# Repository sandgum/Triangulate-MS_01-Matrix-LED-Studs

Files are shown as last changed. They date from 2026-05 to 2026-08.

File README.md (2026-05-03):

# MatrixStuds

## Description
Tiny 10x10mm ear studs (inspired by Mitxela) with 16 LEDs on each, arranged in a 4x4 matrix. Each matrix is controlled by an Analog Devices MAX32660 microcontroller paired with a Bosch BMA530 accelerometer to react to orientation changes. Each stud features a tiny 3.7v-3.3v step-down converter to accept rechargeable Li-ion cells. All tied up together in a CNC'd steel enclosure.

Screenshot 2026-04-04 at 11 23 14 am

## PCB (Studs)
### Overview
* 4-layer double-stacked rigid PCB (8 layers when assembled)
* Matrix on one "part" of PCB, other electronics on other "part"
* Features interconnect pads on back of each PCB to interface between the two "parts"
* 0.4mm thickness, 0.8mm total stacked thickness
* Features 1mm pads for programming, power pins

### Schematic
Screenshot 2026-04-04 at 11 30 57 am

### PCB Layout
Screenshot 2026-04-04 at 11 31 59 am

*Top Layer*

Screenshot 2026-04-04 at 11 32 11 am

*Bottom Layer*

Screenshot 2026-04-04 at 11 38 30 am

*3D Model (Bottom Side)*

Screenshot 2026-04-04 at 11 38 48 am

*3D Model (Top Side)*

## PCB (Charging Board)
## Overview
* 4-layer double-stacked rigid PCB (8 layers when assembled)
* Side 1:
*   Battery charging circuitry for two batteries (fuel gauge and charger)
*   USB-C Port
*   ATMega328P microcontroller for controlling lights
* Side 2:
*   9x WS2812B 2mm NeoPixel Lights
*   Reset SPDT switch for MCU

### Schematic
Screenshot 2026-05-03 at 11 30 13 am

### PCB Layout
Screenshot 2026-05-03 at 11 30 37 am

*Top Layer*

Screenshot 2026-05-03 at 11 31 29 am

*Bottom Layer*

Screenshot 2026-05-03 at 12 21 00 pm

*3D Model (Top Side)*

Screenshot 2026-05-03 at 12 21 12 pm

*3D Model (Bottom Side)*

## Enclosure
### Overview (Studs)
* CNC stainless steel construction
* Two-part design, one for battery side, one for top side
* Translucent PP diffuser over LED matrix
* Push-lock mechanism two secure both sides
* Permanent power wire going from battery side to top side in accent colour
* Points on back of top side for rotational stability while on ear

### Overview (Charging Dock)
* CNC steel upper construction, 3D-printed plastic lower construction
* Battery charging GND connection made through upper case, positive connection made through insulated copper springs
* Magnets to secure studs
* USB-C charging, SoC indication through adressable RGB strip

### Images (Studs)
Screenshot 2026-04-04 at 11 36 01 am
Screenshot 2026-04-04 at 11 36 17 am
Screenshot 2026-04-04 at 11 36 41 am
Screenshot 2026-04-04 at 11 36 59 am

### Images (Charging Dock)
Screenshot 2026-05-03 at 12 22 40 pm
Screenshot 2026-05-03 at 12 23 12 pm
Screenshot 2026-05-03 at 12 23 26 pm
Screenshot 2026-05-03 at 12 23 36 pm
Screenshot 2026-05-03 at 12 23 51 pm

## Bill of Materials (Coming soon)

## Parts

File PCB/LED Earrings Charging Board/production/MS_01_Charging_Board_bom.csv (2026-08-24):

Designator | Footprint | Quantity | Value | LCSC Part #
C1, C3, C5, C57, C58, C59, C6, C60 | 0201 | 8 | 1uF
C10, C9 | 0201 | 2 | 10pF
C11, C12, C13, C14, C15, C16, C17, C18, C19, C20 | 0201 | 10 | 100nF
C2, C4 | 0201 | 2 | 4.7uF
C7, C8 | 0201 | 2 | 22pF
D1, D2, D3, D4, D5, D6 | 0201 | 6 | LED
D10, D11, D12, D13, D14, D16, D17, D18, D9 | LED_WS2812B-2020_PLCC4_2.0x2.0mm | 9 | WS2812B-2020
J1_2, J1 | HRO_TYPE-C-31-M-12 | 2 | TYPE-C-31-M-12
Q3, Q4, Q5, Q6, Q7, Q8 | SOT-23 | 6 | BSS138
R1, R11, R12, R2 | 0201 | 4 | 1.5k
R10, R4, R5, R8 | 0201 | 4 | 1.18k
R22, R23, R24, R25, R26, R27, R28, R29, R3, R30, R31, R32, R33, R34, R35, R36, R37, R38, R39, R40, R41, R42, R43, R44, R9 | 0201 | 25 | 10K
R6, R7 | 0201 | 2 | 5.1k
SW1 | SW_SPDT_PCM12 | 1 | SW_SPDT
TP1, TP3 | TestPoint_Pad_D1.5mm | 2 | Battery+
TP10 | TestPoint_Pad_D1.0mm | 1 | DTR
TP11 | TestPoint_Pad_D1.0mm | 1 | 5V
TP12 | TestPoint_Pad_D1.0mm | 1 | RESET_2
TP13 | TestPoint_Pad_D1.0mm | 1 | DOUT_MCU
TP14, TP16, TP17 | TestPoint_Pad_D1.0mm | 3 | TestPoint
TP18 | TestPoint_Pad_D1.0mm | 1 | DIN_LED
TP19 | TestPoint_Pad_D1.0mm | 1 | VCC_LED
TP2, TP4 | TestPoint_Pad_2.0x2.0mm | 2 | GND
TP20 | TestPoint_Pad_D1.0mm | 1 | VCC_O_LED
TP23 | TestPoint_Pad_D1.0mm | 1 | RESET_1
TP5 | TestPoint_Pad_D1.0mm | 1 | MOSI
TP6 | TestPoint_Pad_D1.0mm | 1 | MISO
TP7 | TestPoint_Pad_D1.0mm | 1 | SCK
TP8 | TestPoint_Pad_D1.0mm | 1 | TX
TP9 | TestPoint_Pad_D1.0mm | 1 | RX
U1, U2 | QFN50P300X300X100-17N | 2 | BQ24075RGTR
U12, U13 | 21-0555B_W80B1-1_MXM | 2 | MAX17048X+T10
U3 | QFN-32-1EP_5x5mm_P0.5mm_EP3.1x3.1mm | 1 | ATmega328P-M
U4 | SOT-23 | 1 | XC6206P332MR-G-SOT23 | XC6206P332MR-G
Y1 | OSC_X322516MLB4SI | 1 | X322516MLB4SI

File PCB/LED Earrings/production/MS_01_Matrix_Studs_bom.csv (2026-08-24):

Designator | Footprint | Quantity | Value | LCSC Part #
A1 | BGA6N40P3X2_120X80X59 | 1 | BMA530
C1, C5 | 0201 | 2 | 1uF
C2 | 0402 | 1 | 10uF
C3 | 0201 | 1 | 4.7uF
C4 | 0201 | 1 | 100nF
D1, D10, D11, D12, D13, D14, D15, D16, D2, D3, D4, D5, D6, D7, D8, D9 | 0201 | 16 | LED
MOUSE-BITE-1MM-3MM_4, MOUSE-BITE-1MM-3MM_3, MOUSE-BITE-1MM-3MM_2, MOUSE-BITE-1MM-3MM | mouse-bite-1mm-3mm | 4 | VAL**
R1, R2 | 0201 | 2 | 4.7k
TP1 | TestPoint_Pad_D1.0mm | 1 | SWDIO
TP10, TP18 | TestPoint_Pad_D1.0mm | 2 | P0.5
TP11 | TestPoint_Pad_D1.0mm | 1 | GND
TP12, TP23 | TestPoint_Pad_D1.0mm | 2 | P0.9
TP13, TP6 | TestPoint_Pad_D1.0mm | 2 | P0.8
TP14, TP21 | TestPoint_Pad_D1.0mm | 2 | P0.11
TP15, TP7 | TestPoint_Pad_D1.0mm | 2 | P0.10
TP16, TP8 | TestPoint_Pad_D1.0mm | 2 | P0.7
TP17, TP9 | TestPoint_Pad_D1.0mm | 2 | P0.6
TP19, TP20 | TestPoint_Pad_D1.0mm | 2 | P0.12
TP2 | TestPoint_Pad_D1.0mm | 1 | SWDCLK
TP22 | TestPoint_Pad_D1.0mm | 1 | GND1
TP3 | TestPoint_Pad_D1.0mm | 1 | BAT+
TP4 | TestPoint_Pad_D1.0mm | 1 | BAT-
TP5 | TestPoint_Pad_D1.0mm | 1 | VIO
U1 | 21-100264_90-100089_MXM | 1 | MAX32660GTG+T
U2 | CONV_XCL206B333CR-G | 1 | XCL202B331ER-G

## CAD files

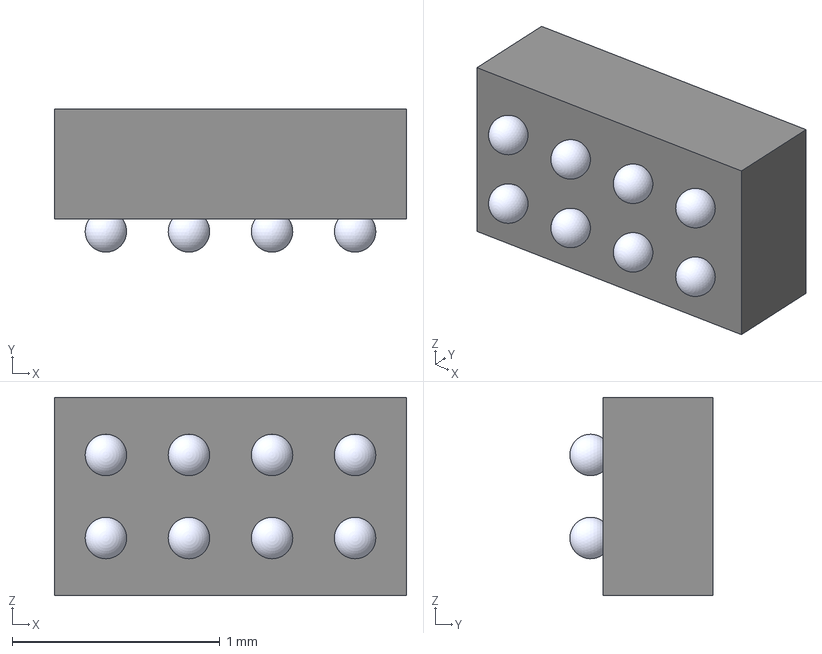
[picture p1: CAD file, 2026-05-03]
PCB/Additional Components/ul_MAX17048X-T10/MAX17048X T10 3D Model STEP.STEP
1.70 x 0.69 x 0.955 mm
Body_Solid1
Body002_Solid1
BALL_0001
BALL_0002
BALL_0003
BALL_0004
BALL_0005
BALL_0006
BALL_0007
BALL_0008

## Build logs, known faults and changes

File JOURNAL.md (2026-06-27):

<!--
  This journal is auto generated by Stasis.
-->

# 5/3/2026 1 AM - Routed Charging Dock PCB

_Time spent: 6h_

I started to route the PCB for the charging dock. When I first imported the footprints for each of the components, they seemed to be too large to fit on the tiny 15x30(ish) millimeter PCB, but that's when I started to employ some crazy Tetris skills to fit everything in. I started with placing the components for the battery charger circuits as efficiently as possible, and I ended up with a very small number of total vias upon routing the tracks.

Screenshot 2026-05-03 at 11.22.06 am

Still, I figured that I would need to take a multi-part board approach in this design by creating two separate boards and stacking them together (just like how the studs themselves are made). The LEDs and the USB-C port took up the most amout of space, so I initially placed them on a separate board to the main charger block.

Placing the MAX17048X+T10 chips and routing their signals, I realised that maybe I would be able to fit almost everything on one board, especially since I had more than enough space left in the middle for a USB-C port and the ATMega328P to comfortably fit in. This is what I ended up doing, with the LEDs and a mysterious switch for the ATMega328P still being located on a separate board. In the remaining spaces left on the main part of the board, I squeezed in test points that will be used for programming and monitoring the signals that go between the MCU and its various peripherals.

Screenshot 2026-05-03 at 11.22.54 am

Screenshot 2026-05-03 at 11.22.33 am

I employed the same stacked board design as I did in the studs themselves, with some test points between the two boards that will be connected together with a low-temp solder after assembly (to make sure any other pre-soldered parts don't fall off). For the connection to GND, I decided not to use a test point but instead used the through-holes required for the shield in the USB-C port on the main board. The through-hole pins extend a bit outwards, so accompanying holes on the PCB fit into them which also provides robust alignment for everything.

Routing everything was quite difficult especially given JLCPCB's minimum via size was quite large compared to the tiny board I had. Nevertheless, I was able to fit in a largely uninterrupted ground plane and robust traces for power to everything as well as multiple test pads for debugging and programming. Considering I use the same 0.4mm minimum 4-layer PCB thickness, the whole board exclusing components will be 0.8mm thick, just enough to fit into the enclosure without serious modifications to it.

I chose to panelise the two parts of the PCB for cheaper assembly costs (just like the studs), and connected them together using a mouse bite footprint.

Now it was time to troubleshoot. I ran the Design Rules Checker and found hundreds of errors. This was, however, mostly due to clearance issues and me forgetting to reduce the allowable pad clearance (as JLCPCB can support it). After edding those rules and clearing up some minor issues, the PCB was fully done!

Screenshot 2026-05-03 at 11.23.34 am






# 4/20/2026 7 AM - Created Charging Dock Schematic

_Time spent: 4.5h_

With the basic outline and features I wanted to include in the charging dock finalised, I started to research the parts which I would include, the first one being the battery charging ICs.

These will be the cornerstone of the dock board, and they need to charge fast without an overly complicated external circuit. After a lot of research (which included charging ICs from Analog Devices and various others from Texas Instruments), I settled on using the BQ24075 from Texas Instruments for a numbr of reasons. First, it has a standalone mode which does not require linking it up to a microcontroller via I2C (which would require extra firmware development for drivers), and it achieves very fast charging speeds at 800mA, which can ideally charge the 40mAh batteries of the earrings in around 3 minutes! This charging current would have to be limited in this use case for safety, as the li-ion batteries would risk potential damage by charging that fast.



Implementing the application circuit for the charging IC was simple, and I made an extra modification by adding a transistor-based logic level shifter to the charging signal output. The reson for this will become apparent later.



Routing the power inputs of the two battery charging chips to the VBUS pins on a USB-C port (and making sure to terminate the CC pins with 5.1k resistors), The board now accomplishes all the functions that I intended it to.



However, I wanted this charging dock board to have some extra functionality, so I decided to include a full microcontroller and a series of lights to show charging status. The simplest MCU chip to implement in the design is the ATMega328P, which comes in a tiny 5x5mm package and comes with Arduino IDE support for easy programming.



This rather overkill MCU will allow for the board to have a series of LED lights, specifically a string of 12 WS2812 NeoPixel RGB Lights for a really nice indicator system. To know the state of charge of the batteries, I opted to use two MAX17048X+T10 fuel gauge chips as they can easily communicate over I2C, have Arduino support through a library, and are absolutely tiny.





Finally, the fuel gauge chips and the battery chargers (remember the logic level shifters?) were connected to the digital I/O of the MCU through logic level shifters, and the whole PCB schematic is now done! Time to stuff all of this into a PCB and see if it actually fits!











# 4/8/2026 4 PM - Modelled charging dock/case

_Time spent: 2h_

The studs themselves were done, so I started creating the charging dock for them that would enable actual daily use. Initially, I wanted to create something like an earbuds case, which has the benefit of having a battery of its own to charge the earbuds on the go. This, however, would require a lot of space, both for a large enough battery to make it worthwhile, and for three separate battery charging circuits (one for the internal battery, and two for the studs). 

Plus, the charging dock will be very small to complement the tiny size of the studs, so fitting all of those extra components in would make for an aesthetically inappealing disproportionate form.

Also, I'm already targeting at least one full day of constant use for the studs, so realistically it makes sense for the user to have a charging dock permanently plugged in at home, and charge their studs when they come back.

Screenshot 2026-04-08 at 9.54.15 pm
Screenshot 2026-04-08 at 9.54.41 pm
Screenshot 2026-04-08 at 9.55.01 pm

So with this use case in mind, I started designing a charging "dock", not a case. I began with two nice cutouts for the battery sections to slide into, where conveniently both the positive and negative contacts for the battery were easily accessible. The case for the stud itself is the negative contact, and the positive contact for the battery is exposed on the outside, so a spring-loaded pogo pin on the dock can easily interface with that, and the metal in the dock can connect to the battery's ground.

Below the space for the studs, I created a plastic bottom cap with enough space for a 15x33mm PCB with two small battery charging circuits and a USB-C power port. The whole assembly has been goven the same yellow-and-silver colour scheme as the studs, which gives it a fun and playful look.

Now I will move on to creating the charging PCB, and then I can finally start developing firmware.





# 4/4/2026 5 AM - Modeled Metal Enclosure

_Time spent: 4h_

After getting the PCB design finalised, I started work on the CNC metal enclosure that everything will be housed in. This has to be extremely small and precise (hence the lack of any 3D printing in this project) and also fulfil the purpose of being jewelry. Since my design will also use a split architecture with the battery being on one piece of the stud and the electronics being on the other side, I would also have to find a way to route power through the user's ear.

I started with the section of the stud which holds the battery, which has a very simple one-piece construction. The LIR1045 battery slots into the enclosure, with the positive contact being exposed outwards and the ground gontact being connected to the metal. On the other side of the enclosure, there is a 1.5mm thick tube for a 1mm thick rod to slide into. This will be how the two sides of the stud connect together.
 
Screenshot 2026-04-04 at 11.20.37 am

I wanted to have this connection be made through screw threads, however that will require twisting the whole stud, which can't be allowed due to the additional positive wire that runs directly between the two halves. I had to come up with a solution to this, which involved a tiny push-lock mechanism between the two halves.

Screenshot 2026-04-04 at 11.19.59 am

There is a small divot in the tube on the battery section in which a corresponding bump on the rod pops into. There are additional channels cut into the rod to allow for bending, effectively creating a rudimentary spring. The size of the cutouts are made as large as possible for easy machineability.

Screenshot 2026-04-04 at 11.21.20 am

Now onto the top section of the stud. This is also a single-piece component, with the exception of a thin PP film on the top to help diffuse the individual LEDs. The geometry for this part is much more complicated, with holes cut out for temporary wires to program the MCU inside. There's also a hole cut out on the side for the battery positive wire to route through.

Screenshot 2026-04-04 at 11.21.51 am

One of the most important features of the top part of the stud is the addition of three small points that face towards the user's ear. These are to constrain the rotation of the top part of the stud by slightly digging into the ear, as any rotation is immediately noticeable due to its square shape. Since the points are only 0.5mm tall, they won't hurt the ear at all, barely being noticeble during daily wear.

Screenshot 2026-04-04 at 11.22.12 am

The final enclosure design of the studs has been confimed, so now it's time to design their charging dock!

Screenshot 2026-04-04 at 11.22.30 am








# 3/27/2026 4 AM - Finished PCB Design

_Time spent: 3.5h_

After designing the first board for each matrix stud (which holds the matrix itself) it was now time to focus my attention towards laying out the main control components on their own "layer" of the board. Squeezing the MCU, the voltage regulator, the accelerometer and the connection pade for all the various signals took some quirky rotation and arrangement of parts, but eventually I was able to fit everything on the board.

Screenshot 2026-03-27 at 3.03.04 pm

The hardest part of this project by far was actually routing all the required signals in only 4 layers, while also having no blind or buried via manufacturing capabilities. This made every via take up space on all layers on the board, and I had to get very close to JLCPCB's minimum copper trace width and via size to pack everything in. This took roughly two hours of brain-breaking work, only for me to be faced with HUNDREDS of errors when I ran KiCAD's Design Rules Checker.

Screenshot 2026-03-27 at 3.03.37 pm

Most of the rule breaches were from copper traces that were mere micrometers too close to other nets, and a lot of errors came from courtyard breaches (which I chose to ignore, as I was definitely breaching the recommended courtyards for each component, but that was the only way to make all of them fit in an 8x8mm rounded square). This took more work, until I finally cleared up all copper shorts and soldermask aperture bridges.

I will be getting JLCPCB to assemble these studs, as they use extremely small 0201 sized passive components. JLC requires a PCB size of at lest 10x10mm for this service, so I grouped both sides of the PCB together with tiny mouse bites. These were also connected to two tabs which provide JLC with enough area to make fiducial holes for PCB assembly.

Screenshot 2026-03-27 at 3.07.42 pm

Now that the final PCB is done, I can export it to a 3D model and start designing the enclosure along with the charging circuit for the earrings!





# 3/24/2026 3 AM - Designed PCB schematic and started PCB design

_Time spent: 3.25h_

After deciding on the basic SMD components for the MatrixStuds, I started to compile together a simple schematic. As the microcontroller, the IMU and the voltage regulator all require a very small number of external components, implementing the necessary application schematics for their operation was quite straightforward.

Screenshot 2026-03-24 at 2.06.32 pm

After that, I created the schematic for the simple 4x4 LED matrix, which uses a total of 8 GPIO pins on the microcontroller. The pins for this matrix are not actually connected to the microcontroller in the schematic, but are connected to touch points that correspond wigth equivalent contacts that connect to the microcontroller. This is my solution to two significant problems:
1. There are not enough layers in a 4-layer board to support the routing and vias for both the control electronics and LED matrix
2. A 2-sided board is pretty much mandatory to minimise space taken up, but that incurs additional assembly costs

Having the control electronics (MCU, accelerometer, voltage regulator) on a separate one-sided board, while having the LEDs on another one-sided board would solve these problems, as when these two boards are stacked up, it effectively makes an 8-layer 2-sided PCB for the price of a 4-layer one-sided PCB.

The touch points are on the backside of each board, and allow the two boards to interface with each other.

A couple more touch points have also been added to the front side of the electronics board to allow for programming and the battery connection.

With the super simple schematic done, it was time to move onto designing the PCB, which, as it turns out, is a completely different beast.

That doesn't really worry me as I start laying out the matrix of LEDs on a really nice 8x8mm square board outline with rounded edges. Routing all the signals is trivial, and there is enough space between each LED to  allow for relatively large vias that are nowhere close to the minimum size JLCPCB can manufacture without a price jump. To make the board look cooler (because let's face it, the whole point of matrix LED studs is aesthetics) the LEDs have been tilted at a 45° angle, which also comes with the benefit of easier routing and a denser matrix.

Screenshot 2026-03-24 at 2.07.30 pm

Screenshot 2026-03-24 at 2.07.40 pm

Now it's time to route the PCB that houses the control electronics, which will be much denser.





# 3/22/2026 3 AM - Initial Design and Component Selection

_Time spent: 3.5h_

One day, I found myself very intrigued by this video from YouTube creator Mitxela (https://www.youtube.com/watch?v=CHoGIvOi-jw) and decided that making some cool matrix earrings would be a fun way to master my skills in the miniaturisation of electronics.


*image credit: mitxela*

However, I wanted my design to be completely custom, and that includes the enclosure. More importantly, I also wanted my design to be as small as possible (less than 10mmx10mm) while still integrating a microcontroller and *some* sensor so that the studs would react to changes in their environment. 

Since these earrings would be so small, I was also prepared to make sacrifices on the actual LED matrix, as having an especially high-resolution matrix in an area less than 1cm^2 would be a waste of power and introduce significant complexity (Also, having an especially dense board would require a lot of vias, which take up additional space as JLCPCB can't manufacture boards with blind or buried vias.

The third unique thing I wanted to have in my design was a rechargeable Li-ion battery, the same as the ones used in wireless earbuds. This also means that I'll have to create a battery charging circuit for the MatrixStuds, probably in a sort of case.

So, with my ideation complete, I set out on a hunt for components that would fit my extremely constrained dimensional requirements. Researching on various forums and articles, I found some strong contenders for what microcontroller I would include. Since this microcontroller would have to have enough memory to load in various animations, and enough computing power to run some sort of algorithm to control the matrix using sensor input, have enough GPIO pins to drive a reasonabler matrix, and consume a small enough emount of power to last at least a whole day from a tiny 25mAh battery, this narrowed the search down significantly. At the end, I settled on the MAX32660 microcontroller, which is quite computationally beefy for its tiny 3x3mm size desppite being one of the most efficient MCUs I could find.



After that, I started looking for some sensor to put in the earrings so that it would actually feel "alive". Initially, I thought about using a light sensor, or a very small microphone to respond to voice, but in the end I chose to go with a ridculously tiny 3-axis accelerometer by Bosch: the BMA530. This sensor is not far from the size of an 0201 resistor, measuring only 1.2mm on its longest axis. This would free up a ton of space on the board, and since it uses Bosch's very easy-to-use Sensor API, it can interface with the microcontroller effortlesly.



As the MAX32660 cannot handle any supply voltages above 3.6V (As it is probably designed to be powered by 3V coin cells), I would have to take the 3.7V nominal voltage from a Li-Po battery and step it down to 3.3V for the components. For this, I chose the XCL202B331ER-G by TOREX for its 2.5x2mm footprint. As for the rest of the components, I will be using 0201 passives where possible, and the LEDs will be 0201-sized in a cool white colour. 

As the MAX32660 package I selected has around 9 usable GPIOs, I will connect the chip to a 4x4 matrix. Yes, I did consider Charlieplexing for way more LEDs, but that would've been a pain to arrange and code for, and would've also increased ther size of the studs.

Since the component list for this thing is so tiny, I can jump straight into modeling the PCB!





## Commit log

2026-04-04 Revise README with detailed PCB and enclosure info
    Updated the description and added sections for PCB and Enclosure details, including images.
2026-04-20 Charging Board PCB, CAD Models
    [LED Earrings Charging Board.kicad_pcb, LED Earrings Charging Board.kicad_sch]
2026-04-20 Add schematic and PCB layout sections to README
    Added schematic and PCB layout sections for the charging board.
2026-05-03 Update PCB and enclosure sections in README
2026-05-03 Update README with new images of charging dock
2026-05-03 Updated CAD files with finished charging dock
    [LED Earrings Charging Board.kicad_pcb, MAX17048X T10 3D Model STEP.STEP]
2026-08-24 Tweaks to PCB
    [LED Earrings Charging Board.kicad_pcb, LED Earrings.kicad_pcb, MS_01_Charging_Board_bom.csv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]
